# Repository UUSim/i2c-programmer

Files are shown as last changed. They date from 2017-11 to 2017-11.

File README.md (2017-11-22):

# Handheld i2c bus programmer (with real time clock)
This repository hosts the Kicad-based design for a handheld i2c bus programmer/scanner with real time clock. The device features:
- DC power (rated 7-12V)
- Powered via i2c bus connector (TBD)
- LCD user interface
- Input via rotary encoder with switch
- It's own clock (on separate i2c bus) + battery backup
- Configurable i2c pullup resistors
- Square wave signal of DS1307 accessible via header

Functions:
- Scan for devices on i2c bus
- Debug i2c protocol
- Set/Read time of internal RTC
- Set/Read time RTC on external i2c bus
- Expose own RTC to external i2c bus
- Communicate with i2c devices on bus

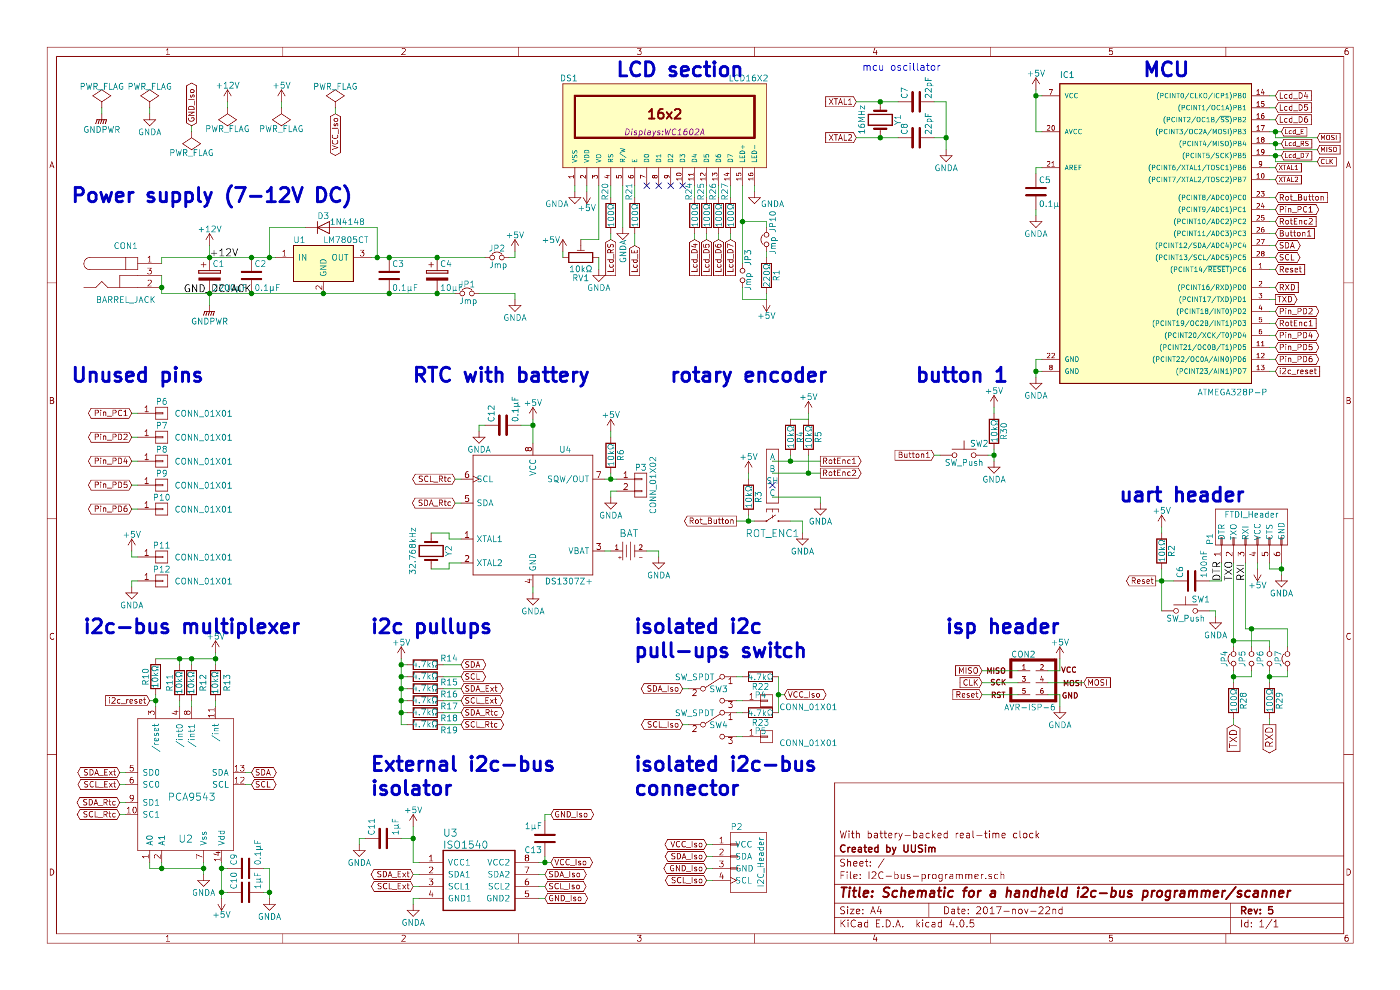
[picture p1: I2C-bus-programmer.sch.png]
Screenshot of project schematic


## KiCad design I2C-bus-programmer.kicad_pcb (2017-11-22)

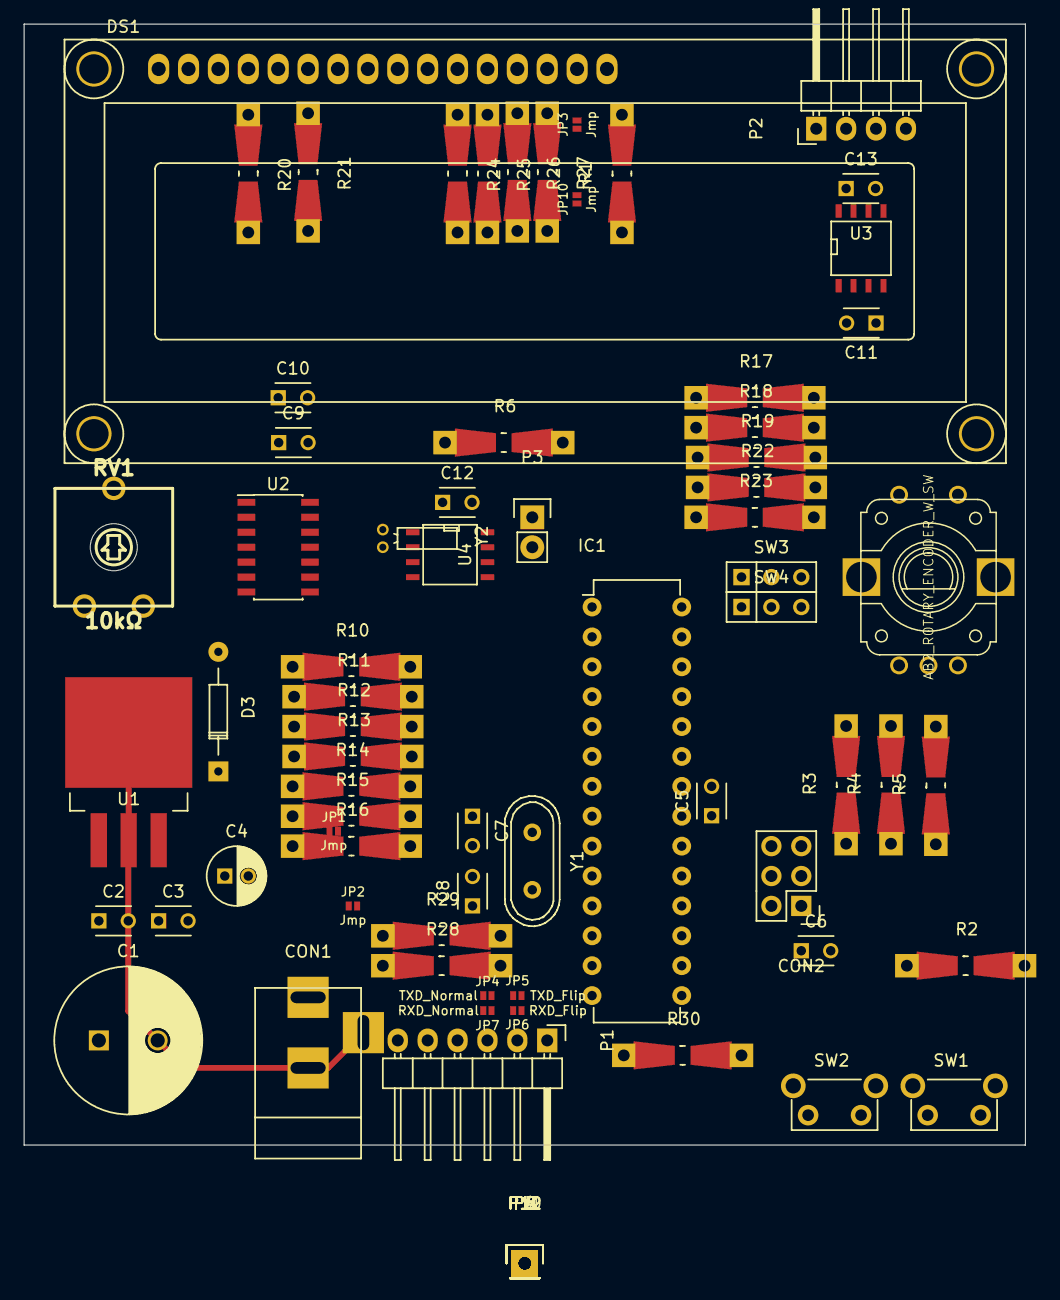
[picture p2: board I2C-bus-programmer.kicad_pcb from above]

Board: 2 copper layers, 85.1 x 95.2 mm, 77 parts (0 on the bottom side), 61 nets.

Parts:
C1: 2200μF; C_Radial_D12.5_L25_P5
C2, C3, C5, C9, C12: 0.1μF; C_Disc_D3_P2.5
C4: 10μF; C_Radial_D5_L11_P2
C6: 100nF; C_Disc_D3_P2.5
C7, C8: 22pF; C_Disc_D3_P2.5
C10, C11, C13: 1μF; C_Disc_D3_P2.5
CON1: BARREL_JACK
CON2: AVR-ISP-6; Pin_Header_Straight_2x03
D3: 1N4148; Diode_DO-35_SOD27_Horizontal_RM10
DS1: LCD16X2; WC1602A
IC1: ATMEGA328P-P; DIP-28_W7.62mm
JP1, JP2, JP3, JP10: Jmp; S_JUMPER_2
JP4: TXD_Normal; S_JUMPER_2
JP5: TXD_Flip; S_JUMPER_2
JP6: RXD_Flip; S_JUMPER_2
JP7: RXD_Normal; S_JUMPER_2
P1: FTDI_Header; Pin_Header_Angled_1x06
P2: I2C_Header; Pin_Header_Angled_1x04
P3: CONN_01X02; Pin_Header_Straight_1x02
P4, P5, P6, P7, P8, P9, P10, P11, P12: CONN_01X01; Pin_Header_Straight_1x01
R1: 220Ω; Resistor_SMD+THTuniversal_0805to1206_RM10_HandSoldering
R2, R3, R4, R5, R6, R10, R11, R12, R13, R30: 10kΩ; Resistor_SMD+THTuniversal_0805to1206_RM10_HandSoldering
R14, R15, R16, R17, R18, R19, R22, R23: 4.7kΩ; Resistor_SMD+THTuniversal_0805to1206_RM10_HandSoldering
R20, R21, R24, R25, R26, R27, R28, R29: 100Ω; Resistor_SMD+THTuniversal_0805to1206_RM10_HandSoldering
ROT_ENC1: AB2_ROTARY_ENCODER_W_SW; AB2_ROTARY_ENCODER_W_SWITCH
RV1: 10kΩ; trimmer_ecp_ca9-v10
SW1, SW2: SW_Push; SW_Tactile_SPST_Angled
SW3, SW4: SW_SPDT; SW_Micro_SPST
U1: LM7805CT; TO-263-3Lead
U2: PCA9543; SOIC-14_3.9x8.7mm_Pitch1.27mm
U3: ISO1540; SOIC-8-N
U4: DS1307Z+; SOIC-8-N
Y1: 16MHz; Crystal_HC49-U_Vertical
Y2: 32.768kHz; Crystal_Round_Horizontal_2mm

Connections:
+5V: C9.1, C10.1, C11.2, C12.2, CON2.2, DS1.2, IC1.7, IC1.20, JP2.2, JP3.2, P1.4, P11.1, R1.2, R2.1, R3.1, R4.1, R5.1, R6.1, R10.2, R11.2, R12.2, R13.2, R14.1, R15.1, R16.1, R17.1, R18.1, R19.1, R30.1, RV1.1, U2.14, U3.1, U4.8
+12V: C1.1, C2.1, CON1.1, D3.1, U1.1
/DTR: C6.2, P1.1
/RXI: JP5.2, JP7.2, P1.3
/TXO: JP4.2, JP6.2, P1.2
Button1: IC1.26, SW2.1
CLK: CON2.3, IC1.19, R27.2
GNDA: C5.2, C7.2, C8.2, C9.2, C10.2, C11.1, C12.1, CON2.6, DS1.1, DS1.5, DS1.16, IC1.8, IC1.22, JP1.2, P1.5, P1.6, P3.2, P12.1, R30.2, ROT_ENC1.2, ROT_ENC1.6, RV1.3, SW1.2, SW2.2, U2.1, U2.2, U2.7, U3.4, U4.4
GNDPWR: C1.2, C2.2, C3.2, C4.2, CON1.2, CON1.3, JP1.1, U1.2
GND_Iso: C13.2, P2.3, U3.5
Lcd_D4: IC1.14, R24.2
Lcd_D5: IC1.15, R25.2
Lcd_D6: IC1.16, R26.2
Lcd_E: CON2.4, IC1.17, R21.2
Lcd_RS: CON2.1, IC1.18, R20.2
unnamed: C3.1, C4.1, D3.2, JP2.1, U1.3
unnamed: C5.1, IC1.21
unnamed: DS1.3, RV1.2
unnamed: DS1.4, R20.1
unnamed: DS1.6, R21.1
unnamed: DS1.11, R24.1
unnamed: DS1.12, R25.1
unnamed: DS1.13, R26.1
unnamed: DS1.14, R27.1
unnamed: DS1.15, JP3.1, JP10.2
unnamed: JP4.1, JP5.1, R28.1
unnamed: JP6.1, JP7.1, R29.1
unnamed: JP10.1, R1.1
unnamed: P3.1, R6.2, U4.7
unnamed: P4.1, SW3.3
unnamed: P5.1, SW4.3
unnamed: R11.1, U2.4
unnamed: R12.1, U2.8
unnamed: R13.1, U2.11
unnamed: R22.2, SW3.1
unnamed: R23.2, SW4.1
unnamed: U4.1, Y2.1
unnamed: U4.2, Y2.2
Pin_PC1: IC1.24, P6.1
Pin_PD2: IC1.4, P7.1
Pin_PD4: IC1.6, P8.1
Pin_PD5: IC1.11, P9.1
Pin_PD6: IC1.12, P10.1
RXD: IC1.2, R29.2
Reset: C6.1, CON2.5, IC1.1, R2.2, SW1.1
RotEnc1: IC1.5, R4.2, ROT_ENC1.1
RotEnc2: IC1.25, R5.2, ROT_ENC1.3
Rot_Button: IC1.23, R3.2, ROT_ENC1.4
SCL: IC1.28, R15.2, U2.12
SCL_Ext: R17.2, U2.6, U3.3
SCL_Iso: P2.4, SW4.2, U3.6
SCL_Rtc: R19.2, U2.10, U4.6
SDA: IC1.27, R14.2, U2.13
SDA_Ext: R16.2, U2.5, U3.2
SDA_Iso: P2.2, SW3.2, U3.7
SDA_Rtc: R18.2, U2.9, U4.5
TXD: IC1.3, R28.2
VCC_Iso: C13.1, P2.1, R22.1, R23.1, U3.8
XTAL1: C7.1, IC1.9, Y1.1
XTAL2: C8.1, IC1.10, Y1.2
i2c_reset: IC1.13, R10.1, U2.3

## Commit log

2017-01-16 Added screenshot of schematic
2017-01-16 Initial upload of KiCad project files
    The PCB is not yet routed. Components are placed preliminary.
    [I2C-bus-programmer.kicad_pcb, I2C-bus-programmer.sch]
2017-01-29 Added USB interface to schematic
    Added a B-type usb connector for providing a serial interface to the programmer
    [I2C-bus-programmer.sch]
2017-01-29 Updated schematic info and screenshot.
2017-01-30 Updated USB interface section
    Connected USB interface to different pins, to match pins used for
    v-usb. Added USB D- 2.2k pullup to atmega pin to enable USB
    connects/disconnects through software. Moved 1 pin of the rotary
    encoder onto the INT1 pin.
    [I2C-bus-programmer.sch]
2017-02-05 Completed wiring for PCA9543 i2c bus switch. Added i2c pull-up resistors.
    Wired reset pin of PCA9543 and added required pull-ups to interrupt
    pins. Added pull-ups to internal i2c busses. Added switchable pull-ups
    to isolated i2c bus.
    [I2C-bus-programmer.kicad_pcb, I2C-bus-programmer.sch]
2017-02-06 Added ISP header. Added protection resistors for mcu pins.
    Also added flyback diode for power regulator for when powered via usb.
    [I2C-bus-programmer.kicad_pcb, I2C-bus-programmer.sch]
2017-11-22 Reduced feature creep
    Removed USB connector and circuitry.
    Added proto-pads for unused MCU pins.
    [I2C-bus-programmer.kicad_pcb, I2C-bus-programmer.sch]
2017-11-22 Updated readme after removal of USB connector.
